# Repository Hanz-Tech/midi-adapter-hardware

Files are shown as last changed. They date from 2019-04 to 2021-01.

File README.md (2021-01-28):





# Disclaimer

You are free to:

Share — copy and redistribute the material in any medium or format

Adapt — remix, transform, and build upon the material

________________________________________

Attribution — You must give appropriate credit, provide a link to the license, and indicate if changes were made. You may do so in any reasonable manner, but not in any way that suggests the licensor endorses you or your use.

NonCommercial — You may not use the material for commercial purposes.

___________________________________________

THE HARDWARE IS PROVIDED "AS IS", WITHOUT WARRANTY OF ANY KIND, EXPRESS OR IMPLIED, INCLUDING BUT NOT LIMITED TO THE WARRANTIES OF MERCHANTABILITY, FITNESS FOR A PARTICULAR PURPOSE AND NONINFRINGEMENT. IN NO EVENT SHALL THE AUTHORS OR COPYRIGHT HOLDERS BE LIABLE FOR ANY CLAIM, DAMAGES OR OTHER LIABILITY, WHETHER IN AN ACTION OF CONTRACT, TORT OR OTHERWISE, ARISING FROM, OUT OF OR IN CONNECTION WITH THE HARDWARE OR THE USE OR OTHER DEALINGS IN THE HARDWARE.

_____________________________________________

# Overview

This repo contains both the CAD for the 3D printed cover for the Pocket Operator and the PCB schematic for the adapter. PCB is created using KiCad. Software can be found [here](https://github.com/PO-MIDI-Adapter/midi-adapter-sofware)

## For assmebly instruction please go to the [wiki](https://github.com/PO-MIDI-Adapter/midi-adapter-hardware/wiki)

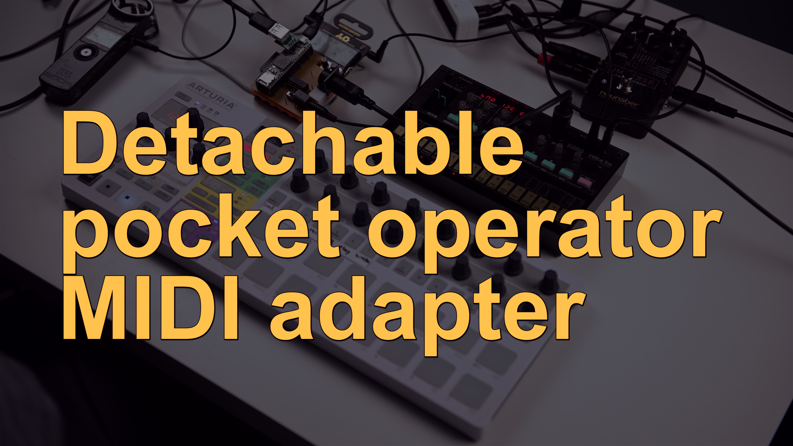
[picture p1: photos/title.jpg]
PO-MA (https://www.youtube.com/watch?v=iIQ18DAJAU0 "PO-MA")


# Photos

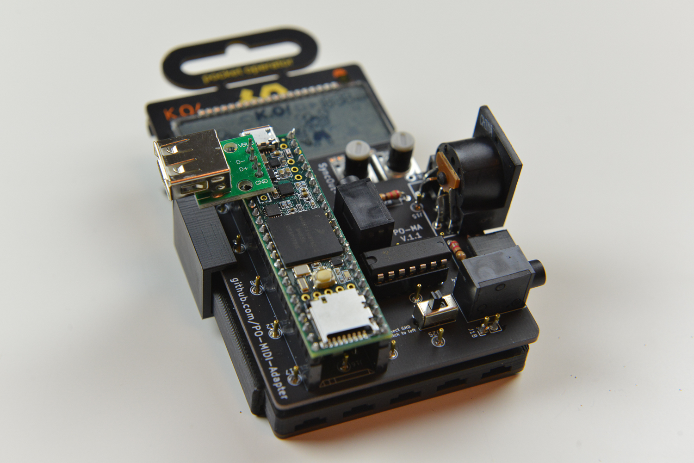
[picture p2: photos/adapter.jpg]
Standalone


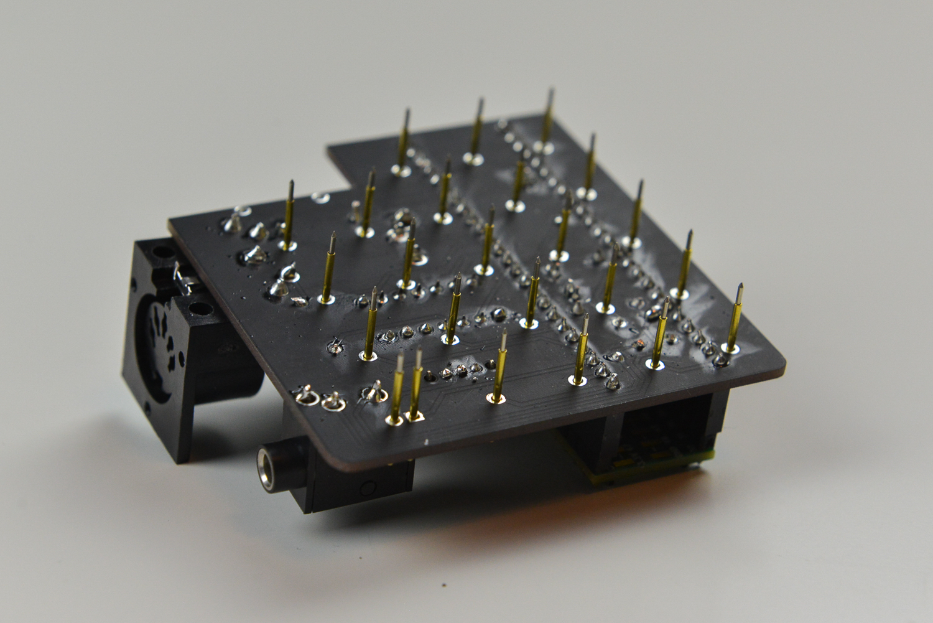
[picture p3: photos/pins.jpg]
Pins


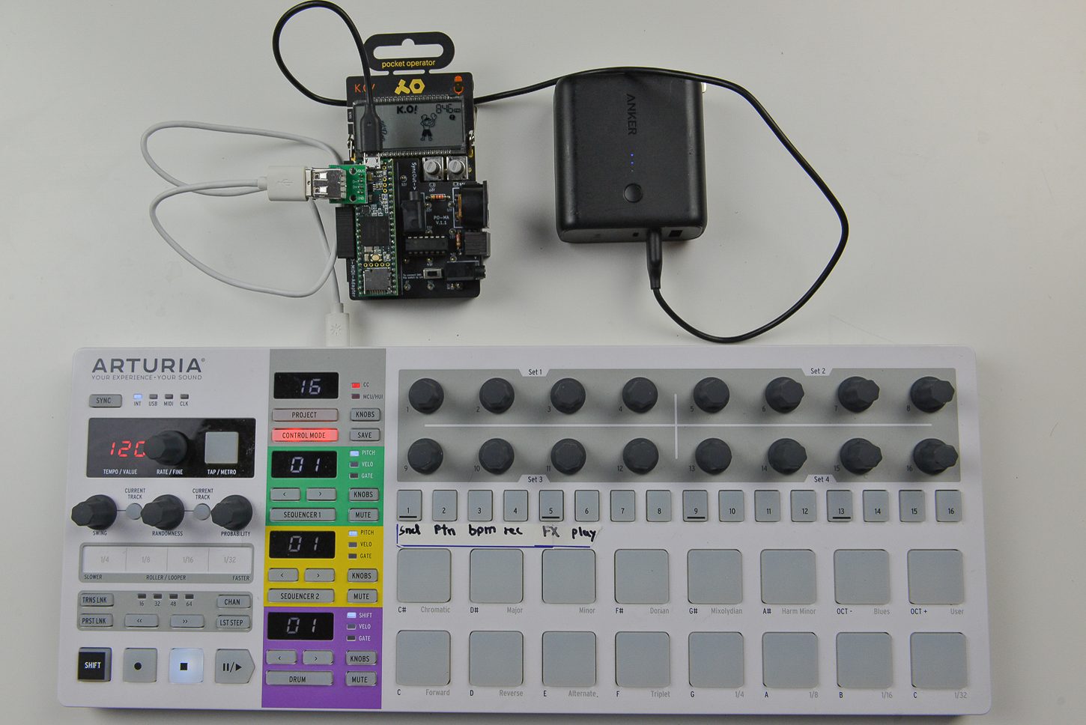
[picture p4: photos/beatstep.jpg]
With volca and beatstep Setup


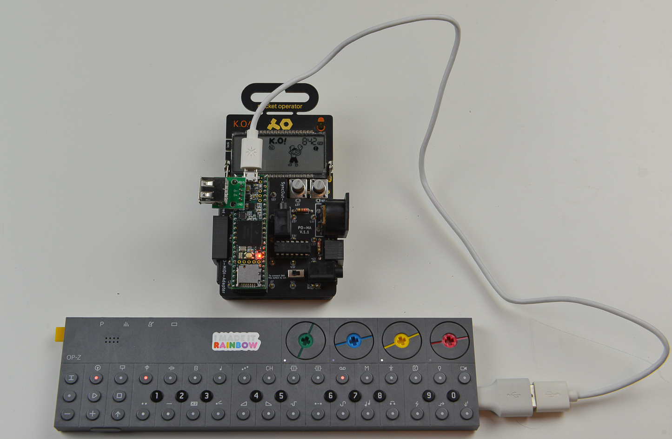
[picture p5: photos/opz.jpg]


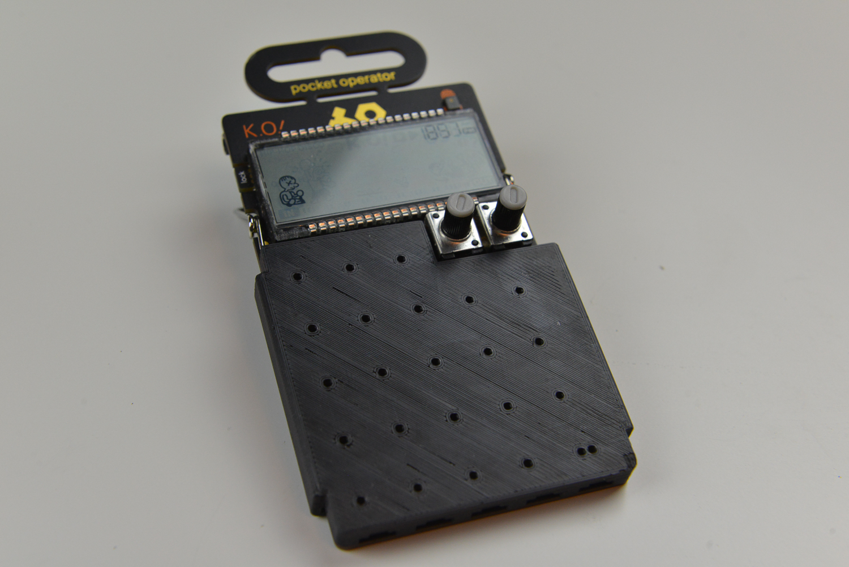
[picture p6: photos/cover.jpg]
Cover


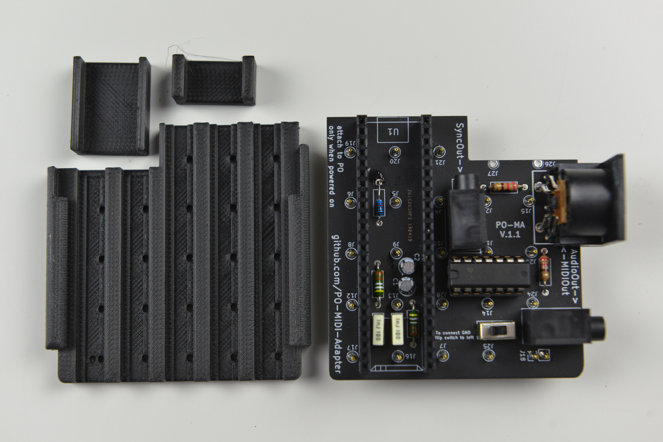
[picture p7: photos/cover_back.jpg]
Cover


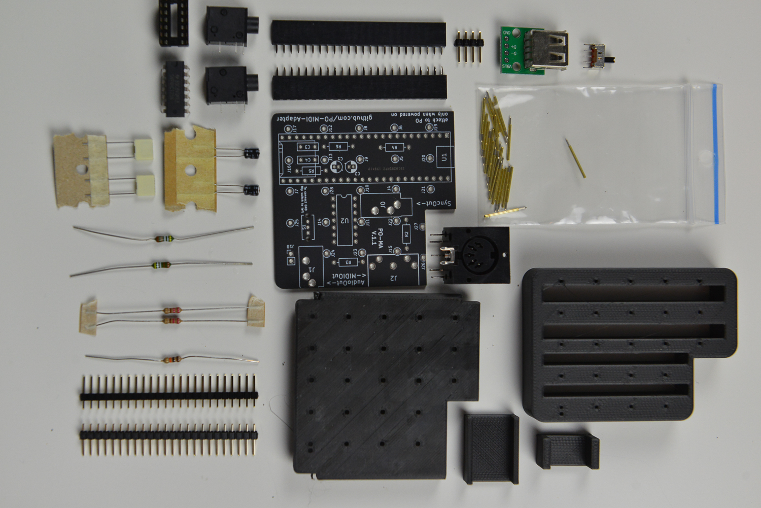
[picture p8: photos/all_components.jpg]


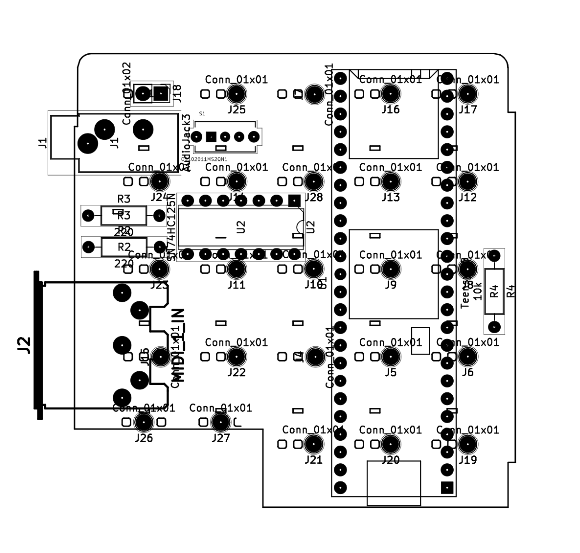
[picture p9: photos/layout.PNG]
Layout


# BOM

1. 1 x PCB board
2. 1 x 3D printed cover (Found in the cad folder)
3. 1 x Holder Left (Found in the cad folder)
4. 1 x Holder right (Found in the cad folder)
5. 25 x P75-B1 pogo pins [ebay](https://www.ebay.ca/itm/50pcs-P75-B1-Dia-1-02mm-100g-Cusp-Spear-Spring-Loaded-Test-Probes-Pogo-Pin/191960357788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)
6. 1 x USB-Host breakout [ebay](https://www.ebay.com/itm/USB-Female-Power-Module-USB-Type-A-Female-Breakout-Converter-Board-Breadboard/272351358553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)

In addition, you would need the following electronics from Digikey (bom.csv)

|Digikey |FIELD2 |FIELD3 |FIELD4  |FIELD5 |
|---|---|---|---|---|
|Manufacturer Part Number|Manufacturer |Digi-Key Part Number|Quantity|Description |
|SN74HC125N |Texas Instruments |296-1572-5-ND |1 |IC BUFFER NON-INVERT 6V 14DIP |
|A 14-LC-TT |Assmann WSW Components |AE9989-ND |1 |CONN IC DIP SOCKET 14POS TIN |
|OS102011MS2QN1 |C&K |CKN9565-ND |1 |SWITCH SLIDE SPDT 100MA 12V |
|SDS-50J |CUI Inc. |CP-2350-ND |1 |CONN RCPT FMALE DIN 5POS SOLDER |
|DEV-14057 |SparkFun Electronics |1568-1442-ND |1 |TEENSY 3.6 W/OUT HDRS K66 EVAL  |
|SJ1-3533NG |CUI Inc. |CP1-3533NG-ND |2 |CONN JACK STEREO 3.5MM R/A |
|CF14JT220R |Stackpole Electronics Inc  |CF14JT220RCT-ND |2 |RES 220 OHM 1/4W 5% AXIAL |
|CF14JT10K0 |Stackpole Electronics Inc  |CF14JT10K0CT-ND |3 |RES 10K OHM 1/4W 5% AXIAL |
|PPTC241LFBN-RC |Sullins Connector Solutions|S7022-ND |2 |CONN HDR 24POS 0.1 TIN PCB |
|PRPC028SACN-RC |Sullins Connector Solutions|S1131EC-28-ND |2 |CONN HEADER VERT 28POS 2.54MM |
|R82EC1100SH50J |KEMET |399-11751-ND |2 |CAP FILM 1000PF 5% 100VDC RADIAL|
|UMA1C100MDD1TP |Nichicon |493-10458-1-ND |2 |CAP ALUM 10UF 20% 16V RADIAL |
|CF14JT5K10 |Stackpole Electronics Inc  |CF14JT5K10CT-ND |2 |RES 5K OHM 1/4W 5% AXIAL |

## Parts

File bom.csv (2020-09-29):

Digikey
Manufacturer Part Number | Manufacturer | Digi-Key Part Number | Quantity | Description | Component Number on PCB
SN74HC125N | Texas Instruments | 296-1572-5-ND | 1 | IC BUFFER NON-INVERT 6V 14DIP | U2
A 14-LC-TT | Assmann WSW Components | AE9989-ND | 1 | CONN IC DIP SOCKET 14POS TIN | U2
OS102011MS2QN1 | C&K | CKN9565-ND | 1 | SWITCH SLIDE SPDT 100MA 12V | S1
SDS-50J | CUI Inc. | CP-2350-ND | 1 | CONN RCPT FMALE DIN 5POS SOLDER | J2
DEV-14057 | SparkFun Electronics | 1568-1442-ND | 1 | TEENSY 3.6 W/OUT HDRS K66 EVAL | U1
SJ1-3533NG | CUI Inc. | CP1-3533NG-ND | 2 | CONN JACK STEREO 3.5MM R/A | J1/J0
CF14JT220R | Stackpole Electronics Inc | CF14JT220RCT-ND | 2 | RES 220 OHM 1/4W 5% AXIAL | R3/R2
CF14JT10K0 | Stackpole Electronics Inc | CF14JT10K0CT-ND | 1 | RES 10K OHM 1/4W 5% AXIAL | R4
PPTC241LFBN-RC | Sullins Connector Solutions | S7022-ND | 2 | CONN HDR 24POS 0.1 TIN PCB | U1
PRPC028SACN-RC | Sullins Connector Solutions | S1131EC-28-ND | 2 | CONN HEADER VERT 28POS 2.54MM | U1
R82EC1100SH50J | KEMET | 399-11751-ND | 2 | CAP FILM 1000PF 5% 100VDC RADIAL | C4/C3
UMA1C100MDD1TP | Nichicon | 493-10458-1-ND | 2 | CAP ALUM 10UF 20% 16V RADIAL | C2/C1
CF14JT5K10‎ | Stackpole Electronics Inc | CF14JT5K10CT-ND | 2 | RES 5K OHM 1/4W 5% AXIAL | R5/R6

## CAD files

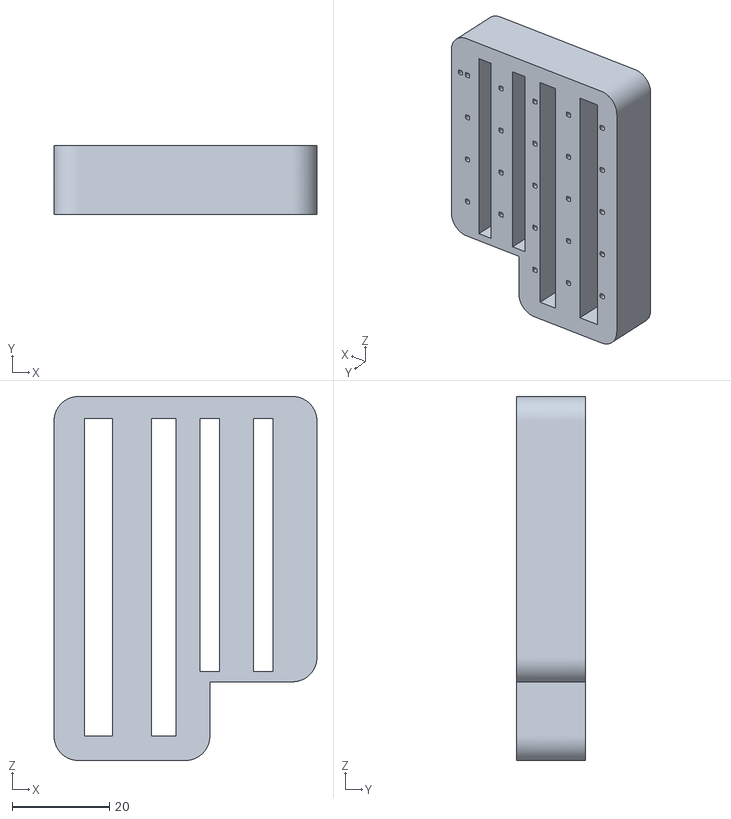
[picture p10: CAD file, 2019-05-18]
cad/pin_holder.stl
54.0 x 14.1 x 74.8

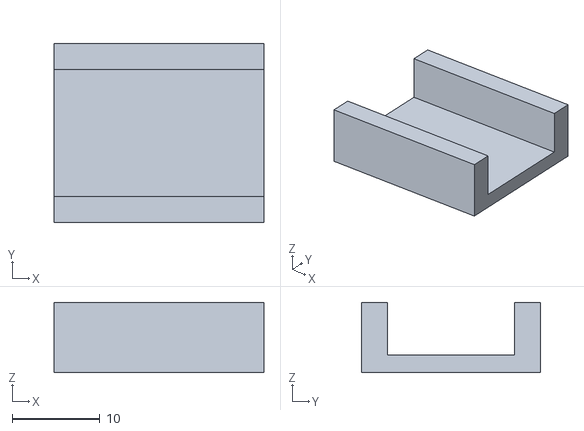
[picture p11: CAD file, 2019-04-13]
cad/holder_left.stl
24.0 x 20.5 x 8.00

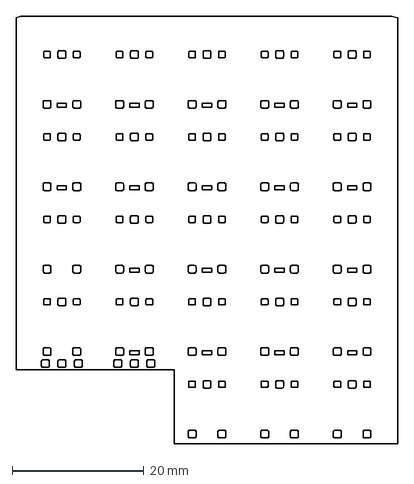
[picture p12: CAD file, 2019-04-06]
cad/front_plate_2.dxf
57.8 x 64.8 mm

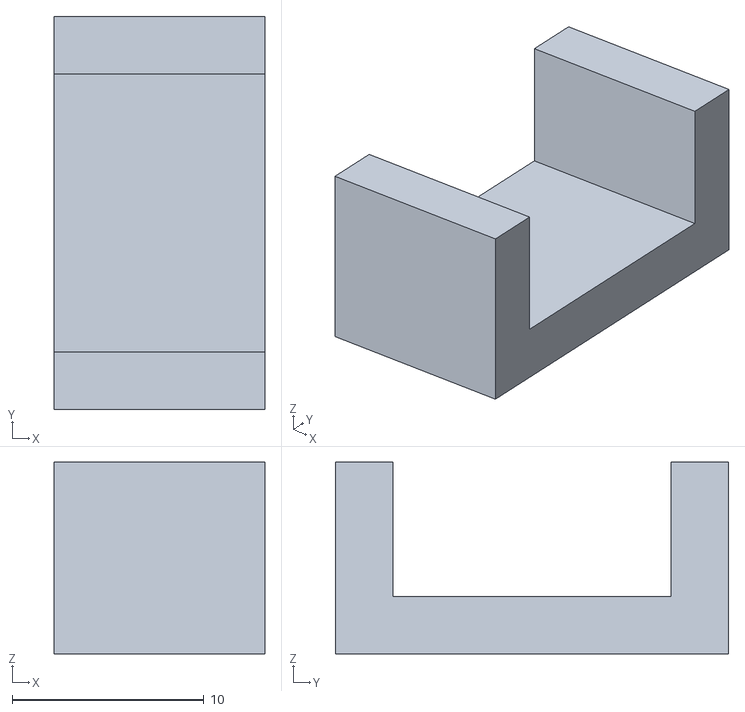
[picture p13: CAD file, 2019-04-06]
cad/holder_right.stl
11.0 x 20.5 x 10.0

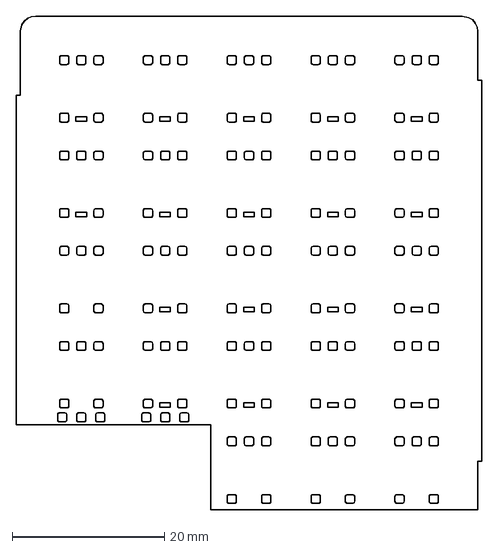
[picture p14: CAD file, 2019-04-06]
cad/front_plate.dxf
61.0 x 64.8 mm

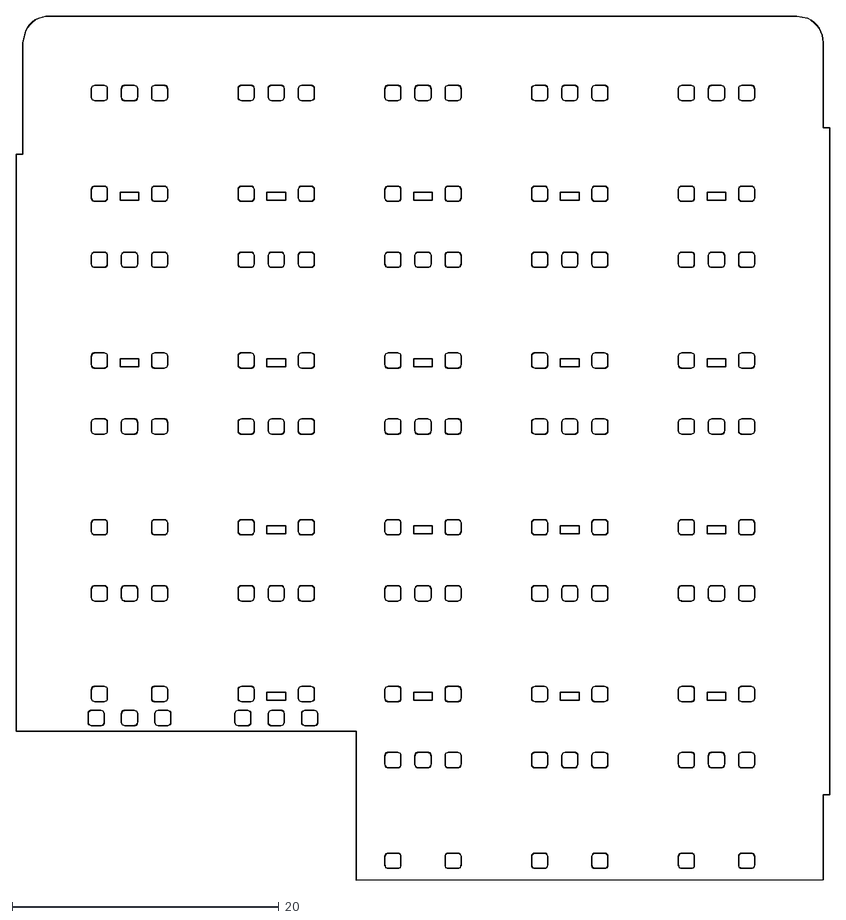
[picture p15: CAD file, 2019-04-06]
cad/#f.dxf
61.0 x 64.8

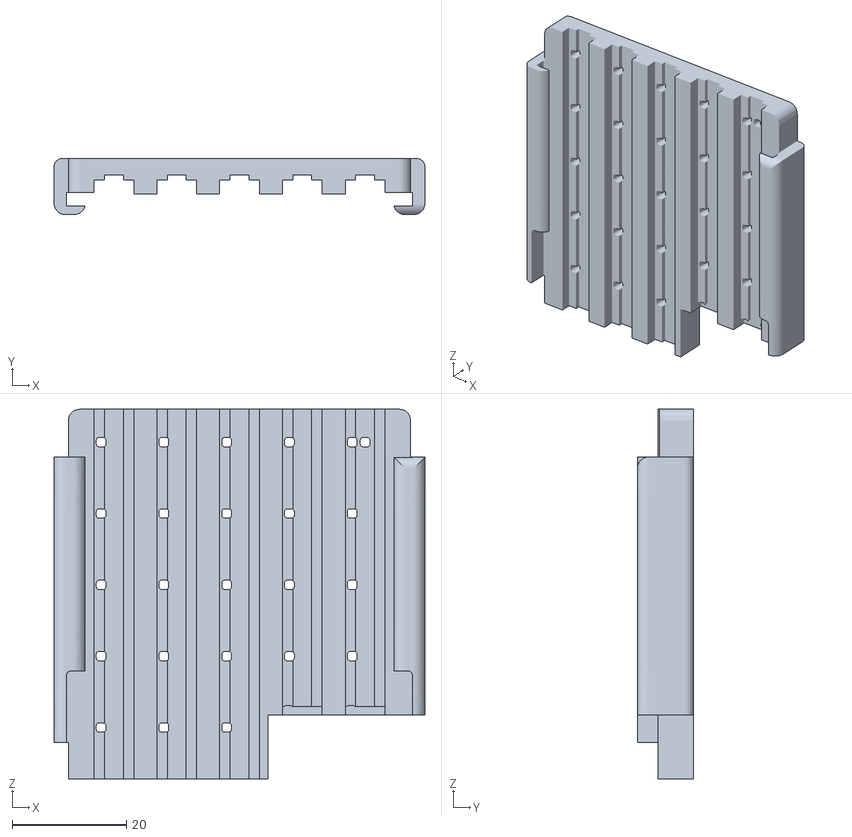
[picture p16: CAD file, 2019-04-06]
cad/cover.stl
65.0 x 9.85 x 64.8

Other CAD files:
cad/f.dxf

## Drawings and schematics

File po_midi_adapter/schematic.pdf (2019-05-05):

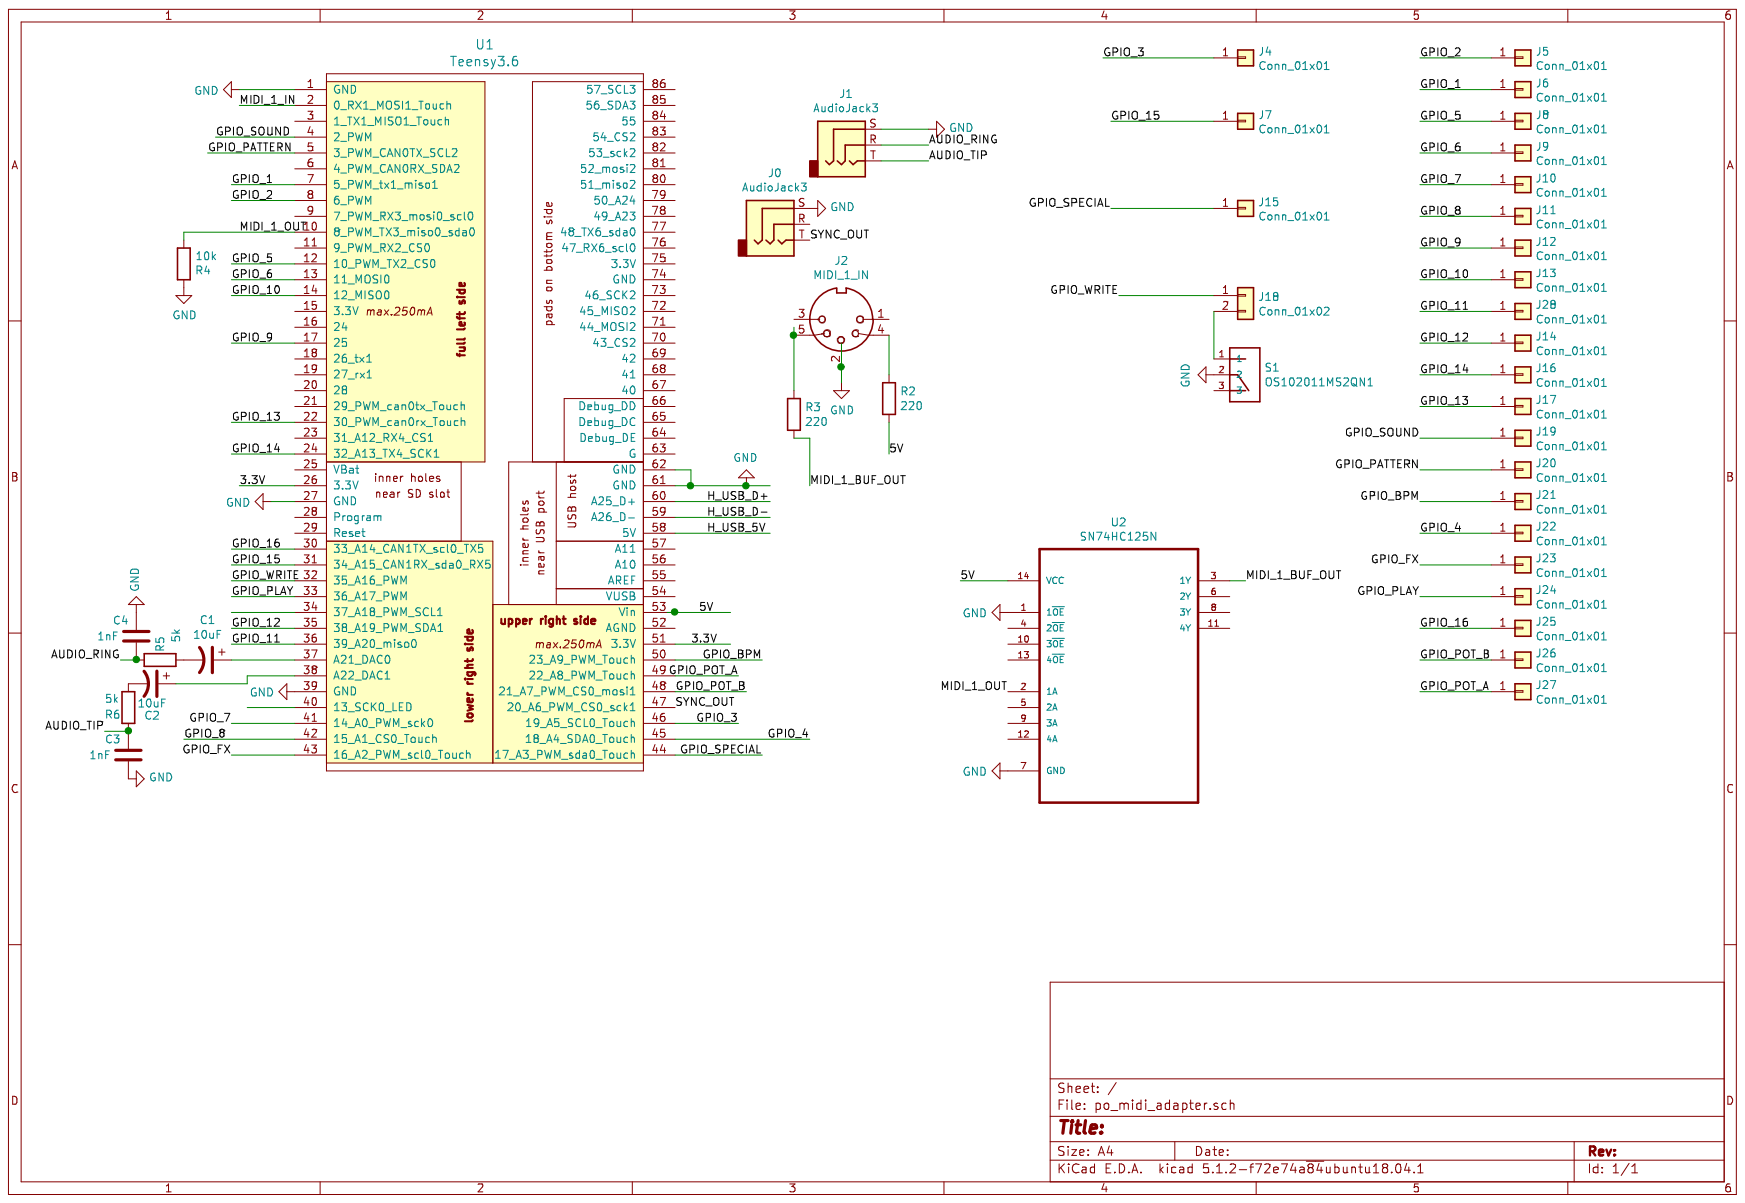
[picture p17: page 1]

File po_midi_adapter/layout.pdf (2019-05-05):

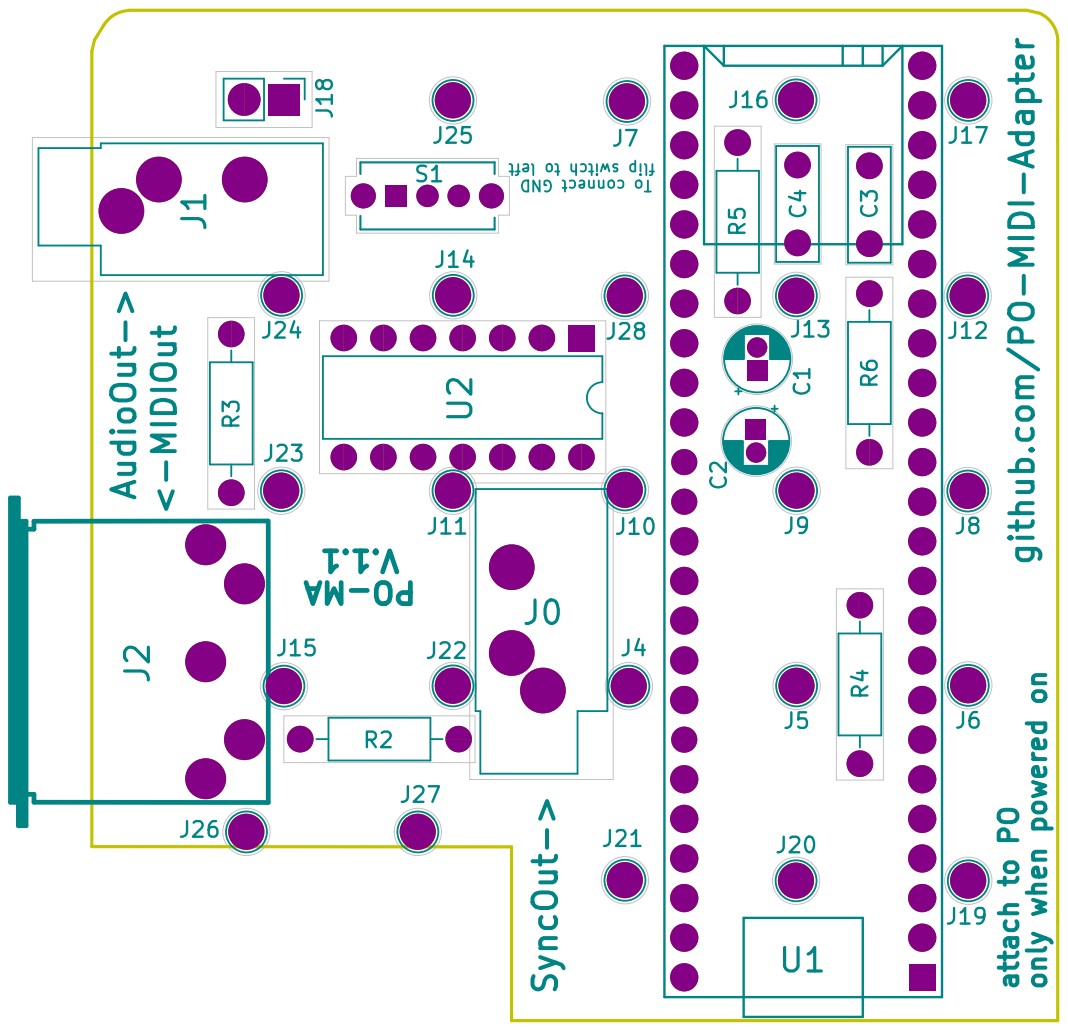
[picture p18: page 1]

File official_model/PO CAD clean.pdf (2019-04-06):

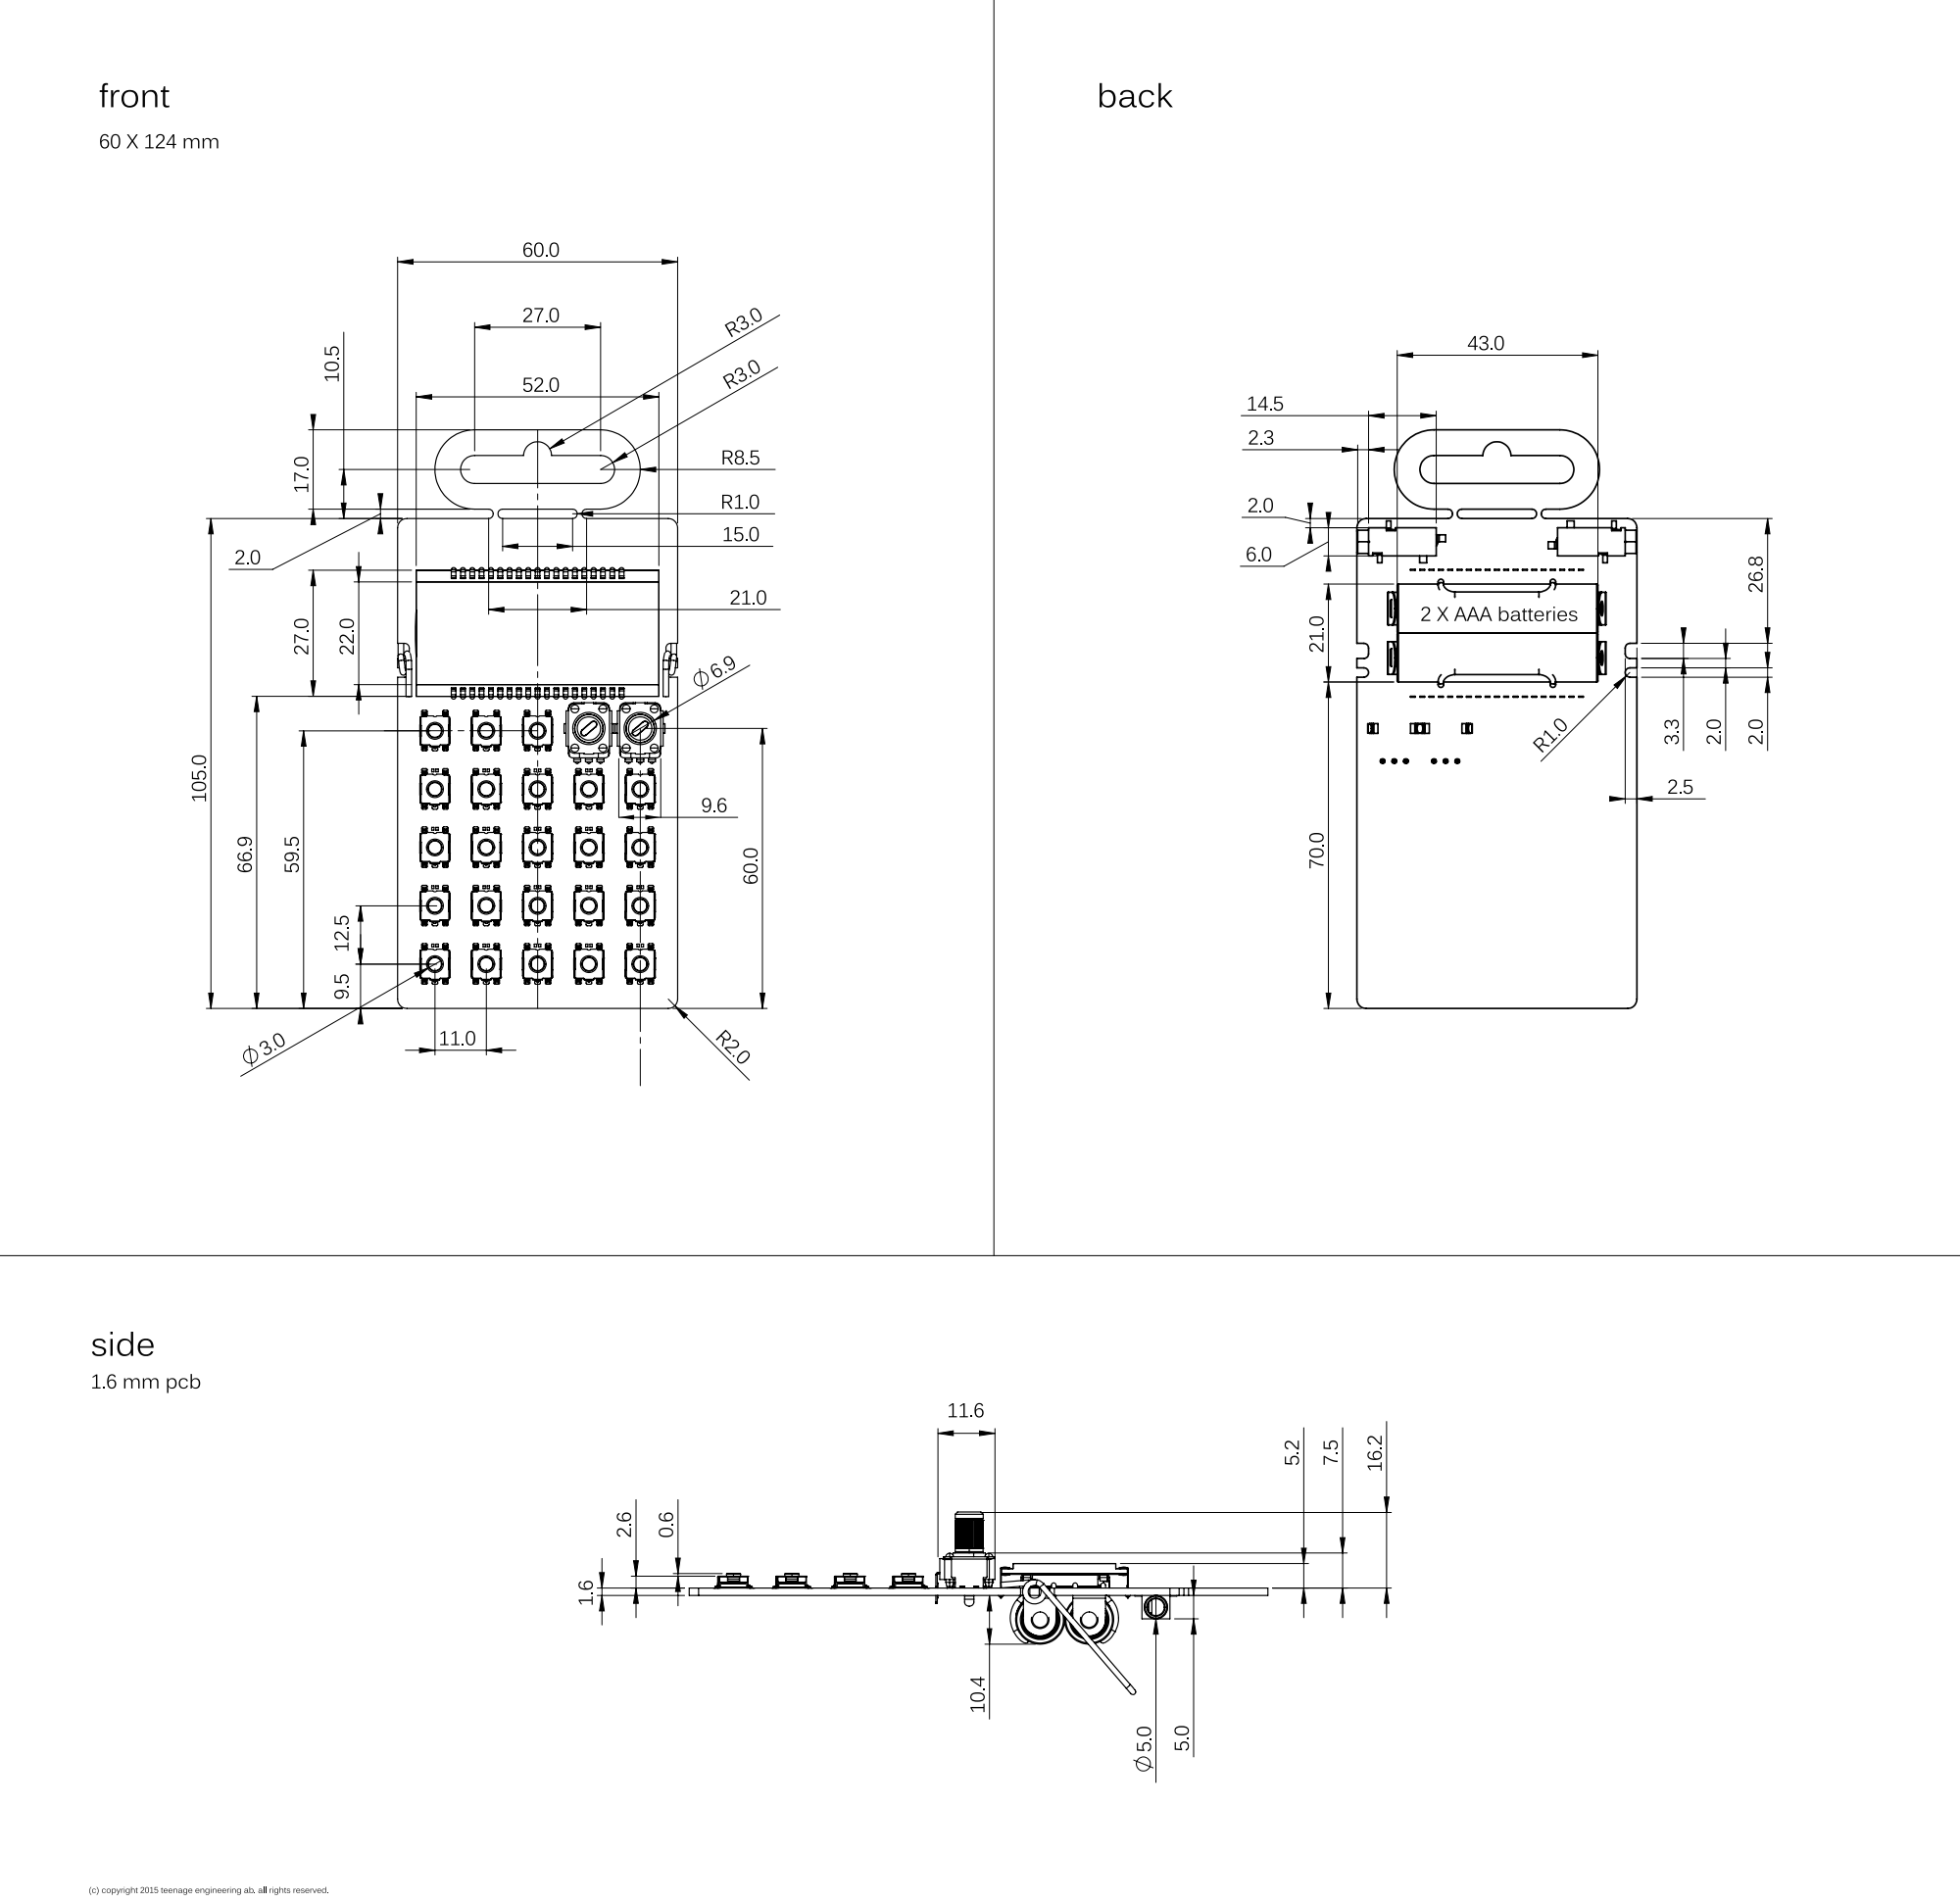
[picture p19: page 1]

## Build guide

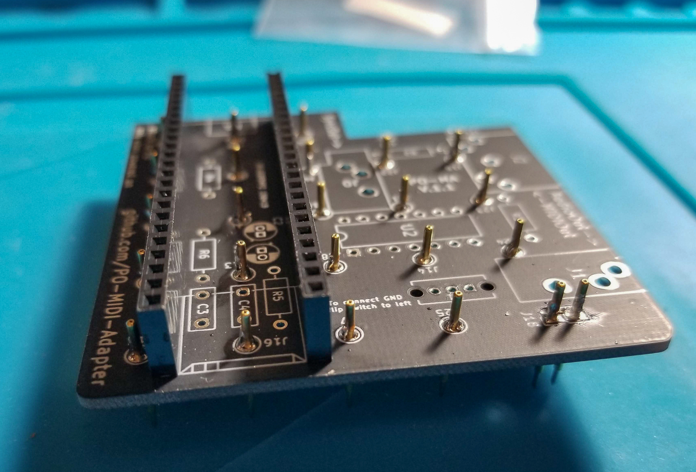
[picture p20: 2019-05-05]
photos/assembly/2.jpg

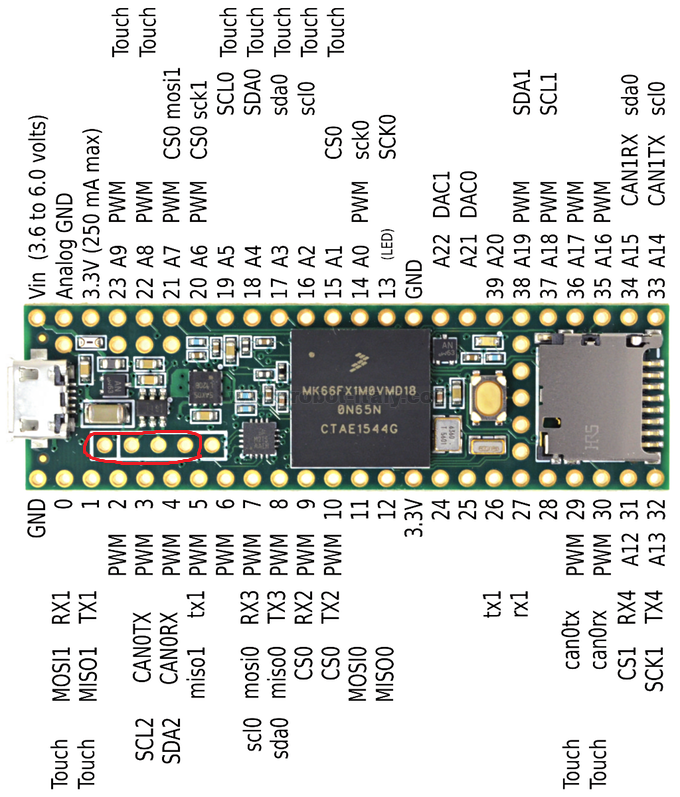
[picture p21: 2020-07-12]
photos/assembly/teensy_pins.png

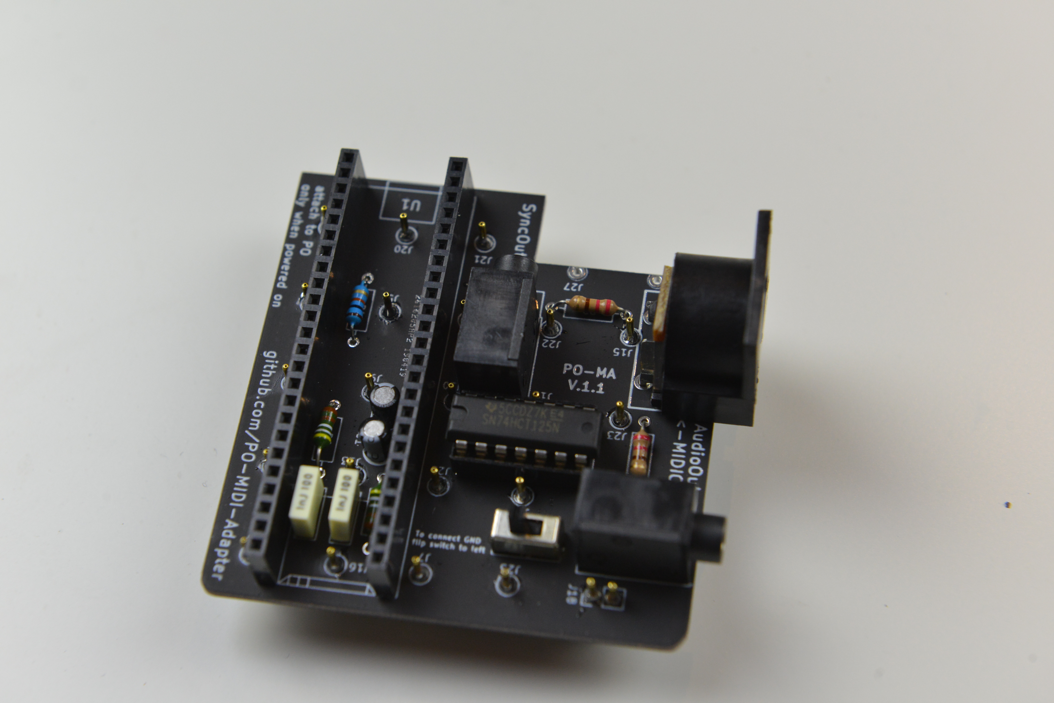
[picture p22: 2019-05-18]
photos/assembly/7.jpg

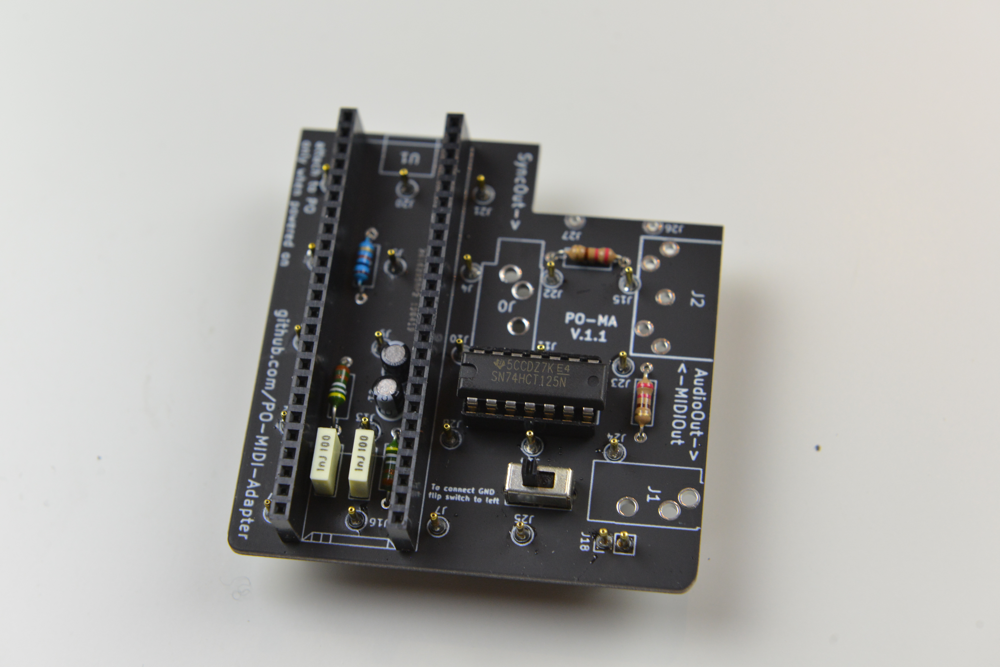
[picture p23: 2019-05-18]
photos/assembly/6.jpg

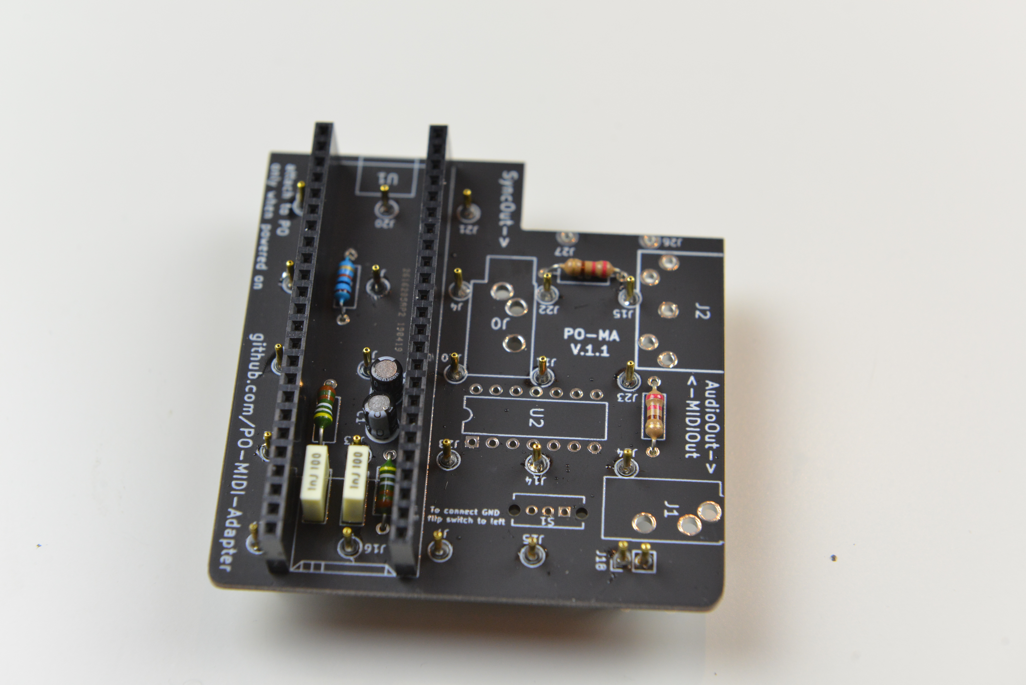
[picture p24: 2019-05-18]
photos/assembly/4.jpg

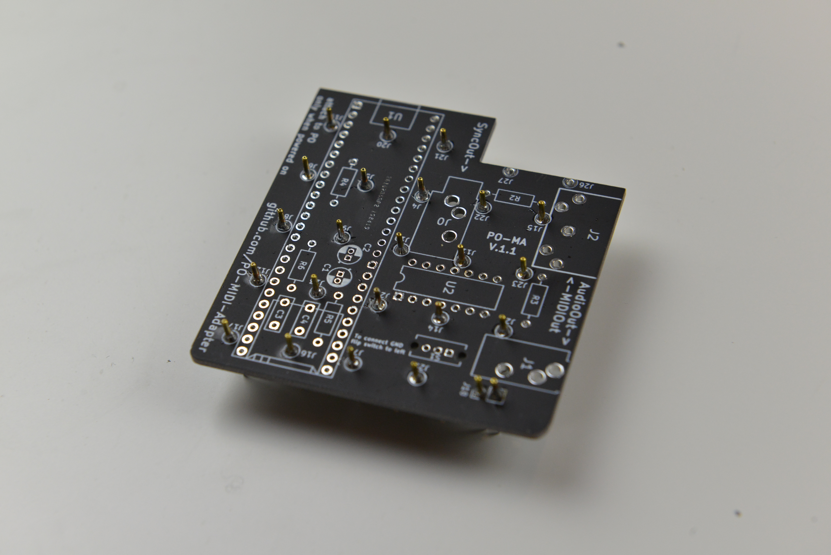
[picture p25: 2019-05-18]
photos/assembly/1.jpg

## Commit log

2019-04-06 inital push
    [#f.dxf, bom.csv, cover.stl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]
2019-04-06 updated bom
    [bom.csv]
2019-04-13 maded left holder thicker
    [holder_left.stl]
2019-04-19 updated to board v1.1
    [po_midi_adapter-B.Adhes.gbr, po_midi_adapter-B.CrtYd.gbr, po_midi_adapter-B.Cu.gbr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]
2019-05-01 new schematic for 1.1
2019-05-05 Added new phoots
    [bom.csv]
2019-05-05 added assembly images
2019-05-18 updated assembly photos
2019-05-18 updated pin holder
    [pin_holder.stl]
2020-07-12 added teensy photo

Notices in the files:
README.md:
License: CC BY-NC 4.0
